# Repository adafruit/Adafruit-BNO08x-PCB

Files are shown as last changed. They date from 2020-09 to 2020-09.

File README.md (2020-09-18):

## Adafruit BNO085  9-DOF Orientation IMU Fusion Breakout PCB

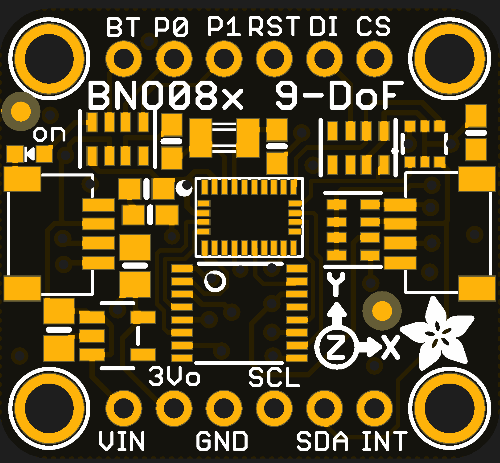
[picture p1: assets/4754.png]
<a href="http://www.adafruit.com/products/4754"><br/>
Click here to purchase one from the Adafruit shop</a>

PCB files for the Adafruit BNO085  9-DOF Orientation IMU Fusion Breakout. 

Format is EagleCAD schematic and board layout
* https://www.adafruit.com/product/4754

### Description

### License

Adafruit invests time and resources providing this open source design, please support Adafruit and open-source hardware by purchasing products from [Adafruit](https://www.adafruit.com)!

Designed by Limor Fried/Ladyada for Adafruit Industries.

Creative Commons Attribution/Share-Alike, all text above must be included in any redistribution. 
See license.txt for additional details.

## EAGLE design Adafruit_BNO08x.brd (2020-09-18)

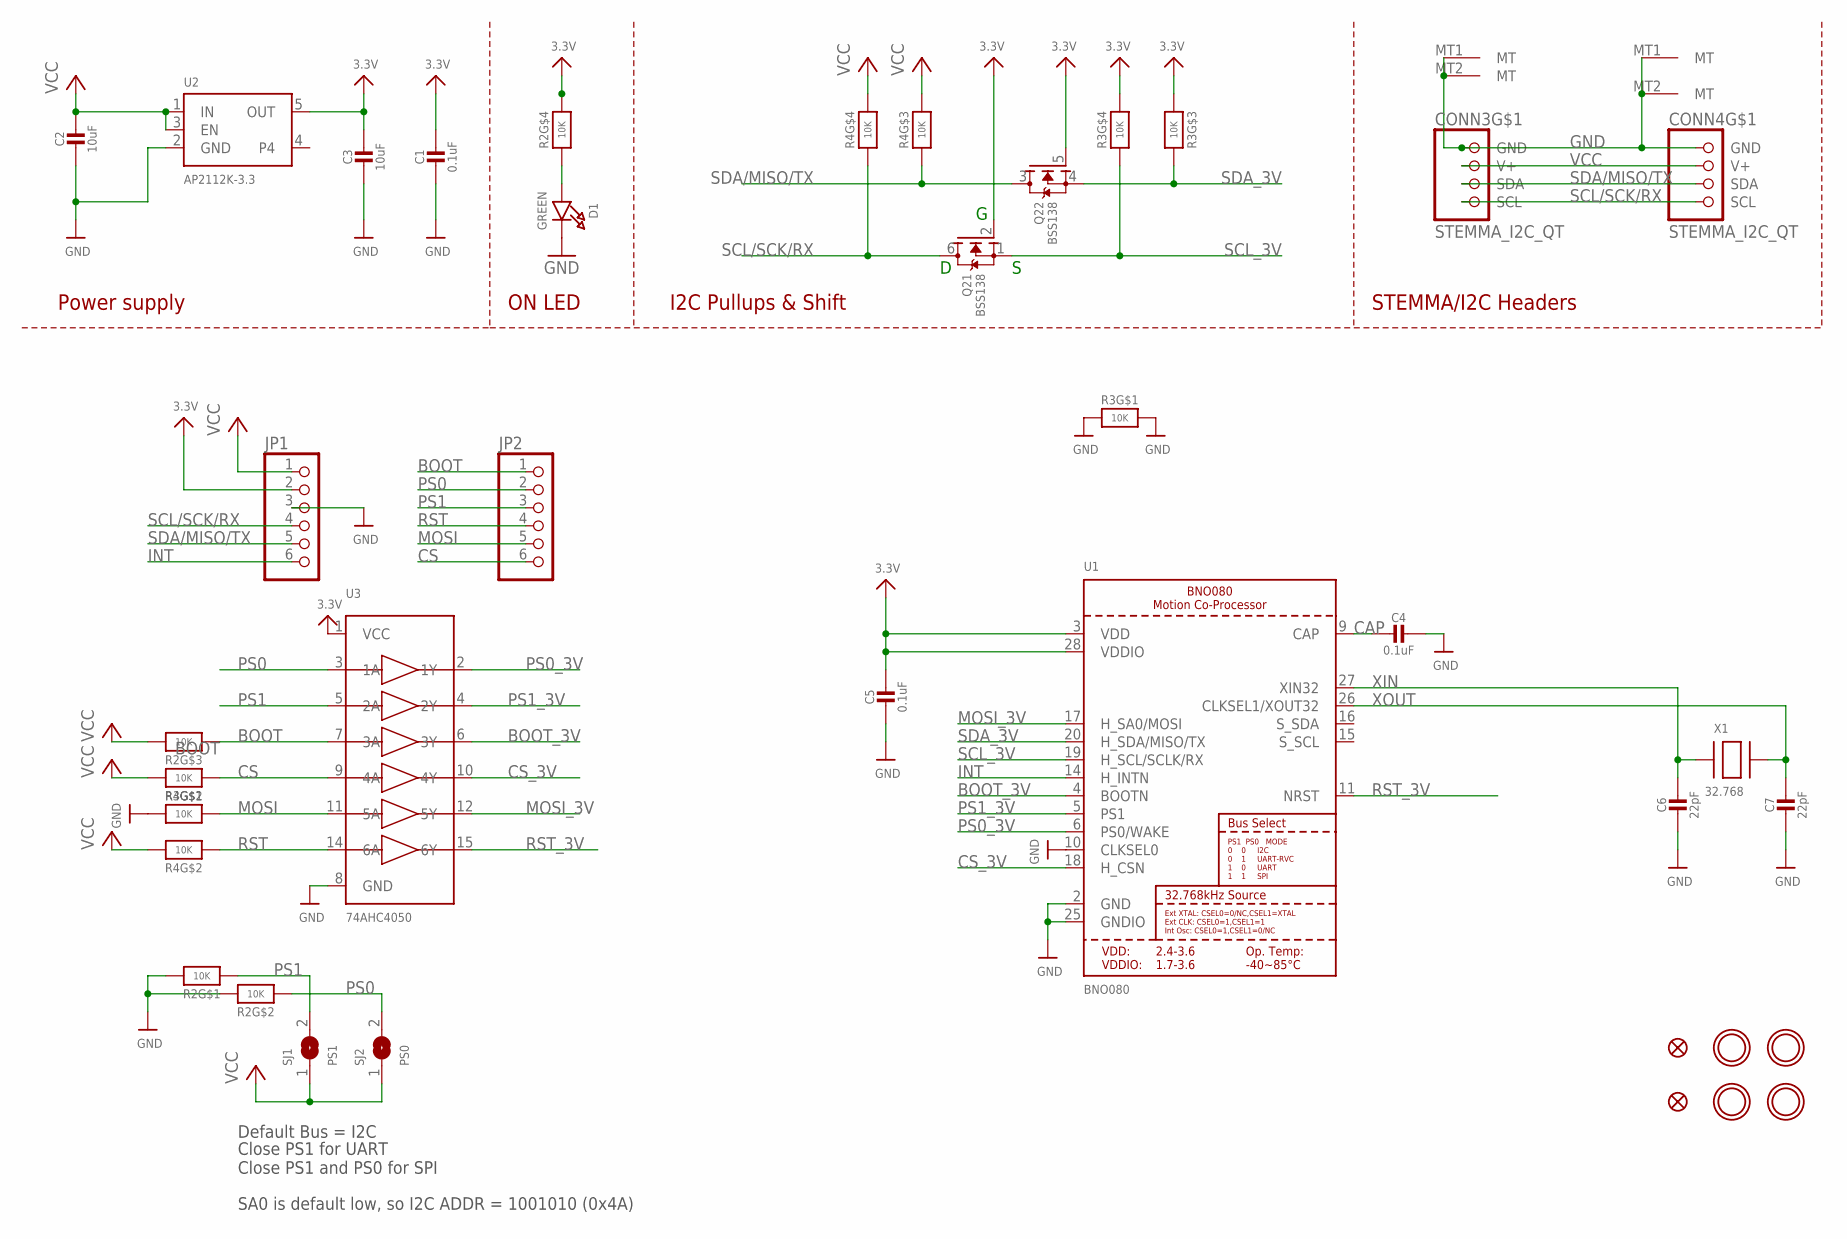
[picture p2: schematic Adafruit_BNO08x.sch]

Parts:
C1, C4, C5: 0.1uF; 0603-NO
C2, C3: 10uF; 0805-NO
C6, C7: 22pF; 0603-NO
CONN3, CONN4: STEMMA_I2C_QT; JST_SH4
D1: GREEN; CHIPLED_0603_NOOUTLINE
FID3, FID4: FIDUCIAL_1MM
JP1, JP2: HEADER-1X670MIL; 1X06_ROUND_70
Q2: BSS138; SOT363
R2, R3, R4: 10K; RESPACK_4X0603
SJ1: PS1; SOLDERJUMPER_ARROW_NOPASTE
SJ2: PS0; SOLDERJUMPER_ARROW_NOPASTE
U1: BNO080
U2: AP2112K-3.3; SOT23-5
U3: 74AHC4050; TSSOP16
U$1, U$17, U$19, U$21: MOUNTINGHOLE2.5; MOUNTINGHOLE_2.5_PLATED
X1: 32.768; XTAL3215

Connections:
3.3V: C1.1, C3.1, C5.1, JP1.2, Q2.2 (G), Q2.5 (G), R2.5 (2), R3.3 (1), R3.5 (2), U1.3 (VDD), U1.28 (VDDIO), U2.5 (OUT), U3.1 (VCC)
BOOT: JP2.1, R2.3 (1), U3.7 (3A)
BOOT_3V: U1.4 (BOOTN), U3.6 (3Y)
CAP: C4.2, U1.9 (CAP)
CS: JP2.6, R4.1, U3.9 (4A)
CS_3V: U1.18 (H_CSN), U3.10 (4Y)
GND: C1.2, C2.2, C3.2, C4.1, C5.2, C6.2, C7.2, CONN3.1 (GND), CONN3.MT1 (MT), CONN3.MT2 (MT), CONN4.1 (GND), CONN4.MT1 (MT), CONN4.MT2 (MT), D1.C, JP1.3, R2.7 (2), R2.8 (2), R3.1, R3.2 (1), R3.8 (2), U1.2 (GND), U1.10 (CLKSEL0), U1.25 (GNDIO), U2.2 (GND), U3.8 (GND)
INT: JP1.6, U1.14 (H_INTN)
MOSI: JP2.5, R3.7 (2), U3.11 (5A)
MOSI_3V: U1.17 (H_SA0/MOSI), U3.12 (5Y)
unnamed: D1.A, R2.4 (1)
PS0: JP2.2, R2.2 (1), SJ2.2, U3.3 (1A)
PS0_3V: U1.6 (PS0/WAKE), U3.2 (1Y)
PS1: JP2.3, R2.1, SJ1.2, U3.5 (2A)
PS1_3V: U1.5 (PS1), U3.4 (2Y)
RST: JP2.4, R4.2 (1), U3.14 (6A)
RST_3V: U1.11 (NRST), U3.15 (6Y)
SCL/SCK/RX: CONN3.4 (SCL), CONN4.4 (SCL), JP1.4, Q2.6 (D), R4.4 (1)
SCL_3V: Q2.1 (S), R3.4 (1), U1.19 (H_SCL/SCLK/RX)
SDA/MISO/TX: CONN3.3 (SDA), CONN4.3 (SDA), JP1.5, Q2.3 (D), R4.3 (1)
SDA_3V: Q2.4 (S), R3.6 (2), U1.20 (H_SDA/MISO/TX)
VCC: C2.1, CONN3.2 (V+), CONN4.2 (V+), JP1.1, R2.6 (2), R4.5 (2), R4.6 (2), R4.7 (2), R4.8 (2), SJ1.1, SJ2.1, U2.1 (IN), U2.3 (EN)
XIN: C6.1, U1.27 (XIN32), X1.P$1
XOUT: C7.1, U1.26 (CLKSEL1/XOUT32), X1.P$2

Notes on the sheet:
I2C Pullups & Shift
STEMMA/I2C Headers
ON LED
Power supply
Default Bus = I2C
Close PS1 for UART Close PS1 and PS0 for SPI
SA0 is default low, so I2C ADDR = 1001010 (0x4A)

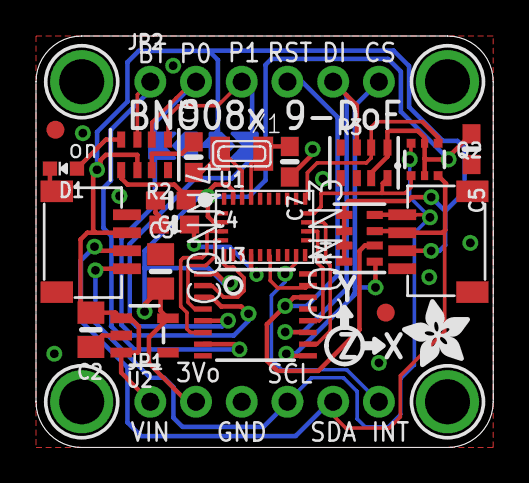
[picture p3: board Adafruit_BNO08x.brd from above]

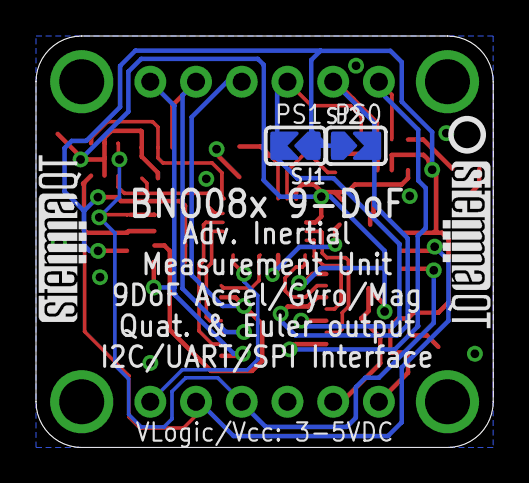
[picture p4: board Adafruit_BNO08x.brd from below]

Board: 2 copper layers, 25.4 x 22.9 mm, 32 parts (5 on the bottom side), 24 nets.

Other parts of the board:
U$22: ADAFRUIT_3.5MM
U$25: PCBFEAT-REV-040
U$30, U$31: STEMMAQT

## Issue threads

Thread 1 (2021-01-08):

No solder jumper present on board for DI (I2C address select) pin

StarWitch, 2021-01-08:
Hi there. I was going through the  [BNO08x Tutorial](https://learn.adafruit.com/adafruit-9-dof-orientation-imu-fusion-breakout-bno085/pinouts) and saw mention of this:

>DI - I2C Address pin. Pulling this pin high or **_bridging the solder jumper on the back_** will change the I2C address from 0x4A to 0x4B

However, looking at the .brd file I noticed there isn't a solder jumper for the DI pin.

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

Was there intended to be one, or is the documentation incorrect?

ladyada, 2021-01-09:
typo in dox. fixed now!

Closed 2021-01-09.

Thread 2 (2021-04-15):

Add LED jumper

adamgarbo, 2021-04-15:
Hi folks,

I would like to make the suggestion to add a jumper to allow users to easily disable/enable the LED on the BNO085. Physically cutting the trace or removing the LED with a hot air rework station is not always an ideal solution for users.

It'd be great to see the LED jumper included as part of the standard STEMMA design to help decrease the current consumption for low power operation.

Cheers,
Adam

ladyada, 2021-04-15:
ok!

Closed 2021-04-15.

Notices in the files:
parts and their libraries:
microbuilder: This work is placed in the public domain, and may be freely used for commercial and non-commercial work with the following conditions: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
